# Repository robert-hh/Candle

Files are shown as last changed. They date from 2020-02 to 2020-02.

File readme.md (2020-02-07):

# Just another candle simulation

I made this little code in 2015, when I had a demand for a LED
based candle, and everything I found was either ugly
or just did not look "natural". The ugly ones are those
you get for almost no money, consisting of a battery pack
and a flicker LED, which switches brightness in a few
steps in fast random times.

So I made this one, based on a Attiny85 which replays
short sequences of brightness variations which I captured
from a real candle. I captured the brightness at a rate
of 10 samples/sec, and the code plays 30 samples/sec,
calculating the interim steps between each captured 
value. 
The repository contains a few captured data sets. Each
data set contains 16 sequences of different length, which
are replayed in random order.

Besides that, the code has two additional functions:

- It checks the voltage of the battery, which in my
case is a Li-Ion type. Below ~2.8 the controller 
gets into sleep mode. That saves the battery from 
damage. The sleep current is below 1 µA.
- You can connect a LDR to check for the environmental
brightness. If connected, the candle will pause e.g.
during the day, saving battery power. At daytime, the
sun is much brighter that the LED.

I use it with a 700mAh rechargeable battery. At an
average current of 7mA, it lasts net for 100 hours, or
about a week, when it is off at daytime.

There are two PCB layouts included, which fit nicely 
on a CR123 battery holder. They use different form
factors of the Attiny85, DIL or SOIC. For the DIL, I
bend the pins sideways and then solder it to the surface 
of the PCB. That way, the PCB sits flat beneath the
battery holder. The circuit is protected against
inserting the battery in the wrong orientation.

For use, I take a sufficiently large candle, diameter >65mm,
let it burn down sich that is has a nice shape, with a cavity
of ~2cm at the top. Then I make a hole in the bottom for the
battery holder with the PCB, connect the LED and the LDR, 
and then I'm done. The only problem with that approach is,
that wax melts in the sun. So do not expose it to direct 
sunlight. Otherwise you get candles in Salvador Dali style.
Even then, I have to replace the wax part sometimes. It gets
dirty after a while.

Note: If you ask, what the relation to Micropython is:
I used a PyBoard 1.0 and a LDR to capture the brightness 
pattern of a real candle, and a Python script for normalizing
the data and cutting it into appropriate segments.

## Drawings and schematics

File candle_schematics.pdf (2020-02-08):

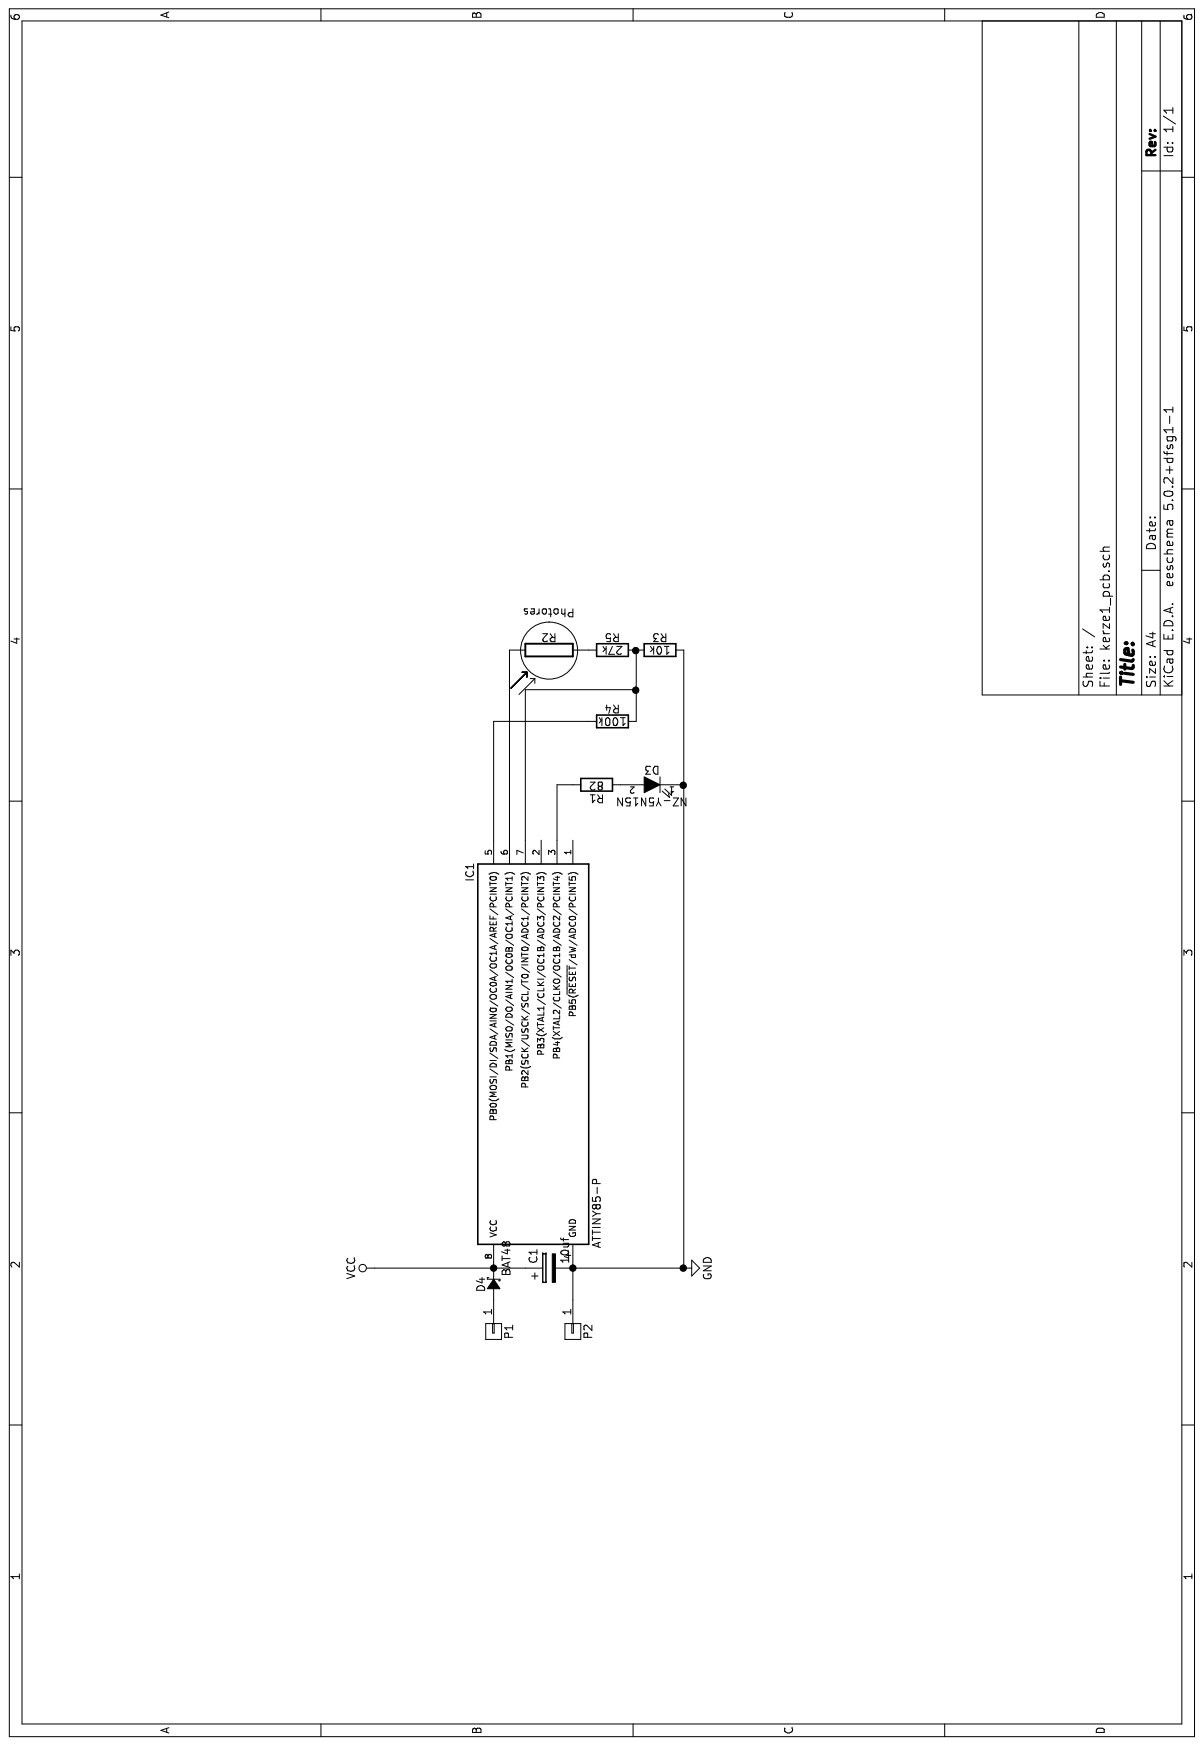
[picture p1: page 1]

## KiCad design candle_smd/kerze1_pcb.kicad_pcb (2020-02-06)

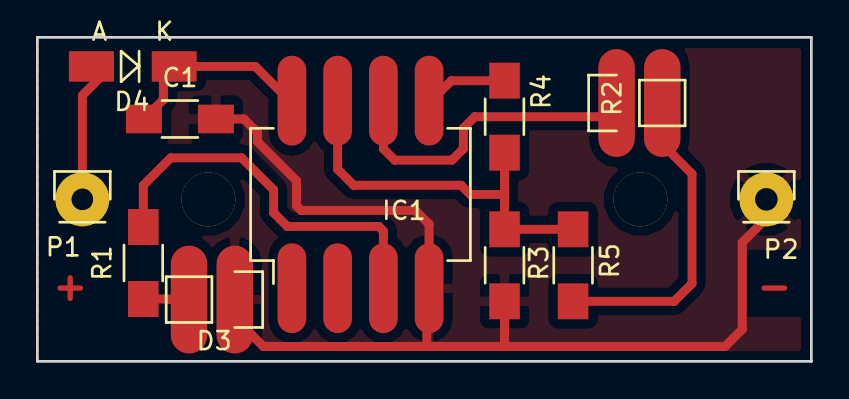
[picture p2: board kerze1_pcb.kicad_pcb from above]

Board: 2 copper layers, 43.0 x 18.0 mm, 13 parts (0 on the bottom side), 9 nets.

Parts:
 : SolderWirePad_single_2mmDrill
 #2: SolderWirePad_single_2mmDrill
C1: 10uf; C_1206_HandSoldering
D3: +LED-; Pin_Header_Straight_1x02
D4: BAT48; MiniMELF_Standard
IC1: ATTINY85-P; DIP-8_W7.62mm_LongPads
P1, P2: Pin_Header_Straight_1x01
R1: 82; R_1206_HandSoldering
R2: Photores; Pin_Header_Straight_1x02
R3: 10k; R_1206_HandSoldering
R4: 100k; R_1206_HandSoldering
R5: 27k; R_1206_HandSoldering

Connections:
GND: C1.2, D3.1, IC1.4, P2.1, R3.2
unnamed: D3.2, R1.1
unnamed: D4.2, P1.1
unnamed: IC1.3, R1.2
unnamed: IC1.5, R4.1
unnamed: IC1.6, R2.1
unnamed: IC1.7, R3.1, R4.2, R5.2
unnamed: R2.2, R5.1
VCC: C1.1, D4.1, IC1.8

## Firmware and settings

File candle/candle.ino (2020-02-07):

// Eine LED mit 256 Stufen
// the setup routine runs once when you press reset:
#include <avr/pgmspace.h>
#include <avr/interrupt.h>
#include <avr/power.h>
#include <avr/sleep.h>
#include <avr/wdt.h>
//#include <avr/cores/tiny/core_adc.h>

// Data captured from a real candle, 1 per byte
#include "data_4.h"

#define VCC_PIN 0 // Ouput for Vcc measuring
#define LDR 1 //  Output controlling LDR
#define LED1 4 // Output of LED
#define SENSE 1 // Number of ADC
#define SENSE_PIN 2 //Number of port PIN for ADC1
#define STATUS 4

uint8_t ldr_state;
uint8_t vcc_state;
uint16_t prev;

#define OFF_LIMIT 850 // 800 // Values normalized for 3.7 V Vbat
#define ON_LIMIT  750 //700
#define VCC_LOW 207  // 2.75V: (Vcc - 0.3) * 1024/12.1
#define VCC_HIGH 220 // 2.9V: (Vcc - 0.3) * 1024/12.1

#define DEBUGLED 0

void wdt_init(void) __attribute__((naked)) __attribute__((section(".init1")));

void wdt_init(void)
{
    MCUSR = 0;
    wdt_disable();

    return;
}

void setup()
{
    // initialize the digital pins
#ifdef _AVR_IOTNX5_H_
    WDTCR |= (1 << WDIE); // reenable interrupt to prevent system reset
    // digitalWrite(LED_BOARD, LOW);
    power_usi_disable();
    ACSR |= _BV(ACD);                         //disable the analog comparator
//    analogReference(ADC_Reference_Internal_1p1);
    analogReference(INTERNAL1V1);
#else
    WDTCSR |= (1 << WDIE); // reenable interrupt to prevent system reset
#endif
    pinMode(LED1, OUTPUT); //LED on Model A
    pinMode(SENSE_PIN, INPUT);
    pinMode(VCC_PIN, INPUT);
    pinMode(LDR, INPUT);
#if DEBUGLED
    pinMode(STATUS, OUTPUT);
#endif
//    digitalWrite(LDR, HIGH);
    ldr_state = 1;  // start with light on
    vcc_state = 1;
// read LDR to seed RNG
    pinMode(LDR, OUTPUT);
    digitalWrite(LDR, HIGH);
    myrand(analogRead(SENSE) & 0xff);
    digitalWrite(LDR, LOW);
    pinMode(LDR, INPUT);

}

// the loop routine runs over and over again forever:
void loop()
{
    uint8_t index, mode;
    uint16_t offset, len, bright, vcc;

// Read VCC
    pinMode(VCC_PIN, OUTPUT);
    digitalWrite(VCC_PIN, HIGH);
    vcc = analogRead(SENSE);
    digitalWrite(VCC_PIN, LOW);
    pinMode(VCC_PIN, INPUT);

// Read LDR
    pinMode(LDR, OUTPUT);
    digitalWrite(LDR, HIGH);
    bright = analogRead(SENSE);
    digitalWrite(LDR, LOW);
    pinMode(LDR, INPUT);

// compensate brightness for changing vcc
    len = ((vcc * 121 + 512) >> 10) + 3;  // 10 times actual Vcc after Diode, rounded
    bright = (bright * 34) / len; // 34 = 10 times (mean Vcc - 0.3V)

#if DEBUGLED
    digitalWrite(STATUS, vcc_state);
#endif

    if (ldr_state != 0 && vcc_state != 0) {  // LED flickers
        wdt_disable();
        index = myrand(0) & 0x0f;
        offset = pgm_read_word_near(offset_tbl + index) >> 1;
        len = (pgm_read_word_near(offset_tbl + index + 1) >> 1) - offset;
        section(offset, len);  // Display
// Test LDR
        if (bright > OFF_LIMIT) { // Daytime, switch off
            ldr_state = 0;
            analogWrite(LED1, 0); // Switch off
        }
// Test VCC
        if (vcc < VCC_LOW) {  // Battery low, switch off
            vcc_state = 0;
            analogWrite(LED1, 0); // Switch off
        }
    } else {

        system_sleep(WDTO_8S, SLEEP_MODE_PWR_DOWN);  // Sleep for 8 sec.

// Test LDR
        if ((ldr_state == 0) && (bright < ON_LIMIT)) {  // Nighttime, switch on
            ldr_state = 1;
        }
// Test VCC, in case the battery recovers
        if ((vcc_state == 0) && (vcc > VCC_HIGH)) {
            vcc_state = 1;
        }
    }
}
// display a section
void section(uint16_t offset, uint16_t len)
{
    int i;
    uint16_t val;

    for (i = 0; i < len; i++) {
        val = pgm_read_byte_near(bright + offset + i); // one values per byte
        if (val < 128) {
            val = (val * val) >> 7;
        } else {
            val = 256 - val;
            val = 255 - ((val * val) >> 7);
        }
        blink(val);  //
    }

}
// display a value
void blink(uint16_t val)
{
    analogWrite(LED1, (val + 2 * prev) / 3); // interim step
    delay(33);
    analogWrite(LED1, (val * 2 + prev) / 3); // interim step
    delay(33);
    analogWrite(LED1, val);
    delay(33);
    prev = val;
}

// Additive RNG along Donal Knuth

uint8_t myrand(uint8_t noise)
{
    static uint8_t set[] = {
        21,  49, 217,  45,   6,  22, 161,  31,  61, 231,
        169,  17,  42, 173, 218, 194, 186, 170,  20,  89,
        44, 138, 163,  58,  30,  34, 220,  31, 134, 130,
        36,  42,  20,  98, 246,  23, 124, 121,  48,  16,
        92,   8,  82,  64,  94,  11, 250,  64, 214, 164,
        88,  87,  67, 225,  23
    };
    static uint16_t k = 54;
    static uint16_t j = 23;
    static uint16_t modulus = 256;
    uint8_t retval;
    int8_t i;

    if (noise != 0) {
        for (i = 0; i < sizeof(set); i++) {
            set[i] = (set[i] + noise) % modulus;
        }
    }

    set[k] = (set[k] + set[j]) % modulus;
    retval = set[k];
    k = (k - 1) % sizeof(set);
    j = (j - 1) % sizeof(set);
    return retval;
}

//****************************************************************
// set system into the sleep state
// system wakes up when wtchdog is timed out
void system_sleep(int duration, int mode)
{
    wdt_enable(duration);
    set_sleep_mode(mode); // sleep mode is set here
    wdt_reset();
#ifdef _AVR_IOTNX5_H_
    WDTCR |= (1 << WDIE); // reenable interrupt to prevent system reset
    ADCSRA &= ~_BV(ADEN);                     //disable ADC
#else
    WDTCSR |= (1 << WDIE); // reenable interrupt to prevent system reset
#endif

    sleep_enable();
    sleep_bod_disable();
    sleep_cpu();
    sleep_disable();                     // System continues execution here when watchdog timed out
#ifdef _AVR_IOTNX5_H_
    ADCSRA |= _BV(ADEN);                     //enable ADC
#endif
}

//****************************************************************

ISR(WDT_vect)
{
    wdt_disable();
}

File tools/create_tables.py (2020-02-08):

#
# nomalize test data

def norm(fname):

    steps = 256
    tailsize = 1000

    liste = []
    with open(fname) as f:
        for l in f:
            liste.append([int(i, 10) for i in l.split(' ')])
        
    print ("Anzahl Daten", len(liste))

## Mittelwerte bestimmen    
    
    minvalue1 = 4096
    maxvalue1 = 0
    minvalue0 = 4096
    maxvalue0 = 0
    avg0 = 0
    avg1 = 0

    for i in liste:
        minvalue0 = min(minvalue0, i[0])
        maxvalue0 = max(maxvalue0, i[0])
        minvalue1 = min(minvalue1, i[1])
        maxvalue1 = max(maxvalue1, i[1])
        avg0 += i[0]
        avg1 += i[1]
            
    avg0 /= len(liste)            
    avg1 /= len(liste)            
    
    print("Min0 = ", minvalue0, ", Max0 = ", maxvalue0, "avg0 = ", avg0)
    print("Min1 = ", minvalue1, ", Max1 = ", maxvalue1, "avg1 = ", avg1)
## Mittelwerte Anfang und Ende bestimmen    
    avghead0 = 0
    avghead1 = 0
    for i in range (0,tailsize):
        avghead0 += liste[i][0]
        avghead1 += liste[i][1]
    
    avgtail0 = 0
    avgtail1 = 0
    for i in range (-(tailsize + 1),-1):
        avgtail0 += liste[i][0]
        avgtail1 += liste[i][1]
    
    avghead0 /= tailsize
    avgtail0 /= tailsize
    avghead1 /= tailsize
    avgtail1 /= tailsize
    print("avghead0 = ", avghead0, ", avgtail0 = ", avgtail0)
    print("avghead1 = ", avghead1, ", avgtail1 = ", avgtail1)
# Kurve kippen    
    avgstep0 = (avgtail0 - avghead0)/len(liste)
    avgstep1 = (avgtail1 - avghead1)/len(liste)
    
    
    for i in range(len(liste)):
        liste[i][0] -= int(i * avgstep0)
        liste[i][1] -= int(i * avgstep1)
## Nochmals Mittelwerte bestimmen
    minvalue1 = 2000000000
    maxvalue1 = 0
    minvalue0 = 2000000000
    maxvalue0 = 0
    
    for i in liste:
        minvalue0 = min(minvalue0, i[0])
        maxvalue0 = max(maxvalue0, i[0])
        minvalue1 = min(minvalue1, i[1])
        maxvalue1 = max(maxvalue1, i[1])
            
    print("Min0 = ", minvalue0, ", Max0 = ", maxvalue0)
    print("Min1 = ", minvalue1, ", Max1 = ", maxvalue1)
    
    avghead0 = 0
    avghead1 = 0
    for i in range (0,tailsize):
        avghead0 += liste[i][0]
        avghead1 += liste[i][1]
    
    avgtail0 = 0
    avgtail1 = 0
    for i in range (-(tailsize + 1),-1):
        avgtail0 += liste[i][0]
        avgtail1 += liste[i][1]
    
    avghead0 /= tailsize
    avgtail0 /= tailsize
    avghead1 /= tailsize
    avgtail1 /= tailsize
    print("avghead0 = ", avghead0, ", avgtail0 = ", avgtail0)
    print("avghead1 = ", avghead1, ", avgtail1 = ", avgtail1)
        
    divide0 = ((maxvalue0 - minvalue0 + 1) / steps)
    divide1 = ((maxvalue1 - minvalue1 + 1) / steps)
    
    avg0 = 0
    avg1 = 0
    for i in range(len(liste)):
        liste[i][0] = int((liste[i][0] - minvalue0) / divide0)
        liste[i][1] = int((liste[i][1] - minvalue1) / divide1)
        avg0 += liste[i][0]
        avg1 += liste[i][1]
    avg0 = int(avg0/len(liste)) 
    avg1 = int(avg1/len(liste)) 
# und nochmals mittelwerte

    minvalue1 = 4096
    maxvalue1 = 0
    minvalue0 = 4096
    maxvalue0 = 0

    for i in liste:
        minvalue0 = min(minvalue0, i[0])
        maxvalue0 = max(maxvalue0, i[0])
        minvalue1 = min(minvalue1, i[1])
        maxvalue1 = max(maxvalue1, i[1])
    
    print("Min0 = ", minvalue0, ", Max0 = ", maxvalue0, "avg0 = ", avg0)
    print("Min1 = ", minvalue1, ", Max1 = ", maxvalue1, "avg1 = ", avg1)
    
    with open(fname + "lr", "w") as f:
        for i in liste:
            f.write("%d %d\n" % (i[0], i[1]))

    
    with open(fname + "f1.h", "w") as f:
        f.write("const PROGMEM  uint8_t bright[] = {")
        for i in range(len(liste)):
            if (i % 20) == 0:
                f.write("\n    ")
            f.write("%d" % liste[i][0])
            if i < len(liste) - 1: 
                f.write(", ")
        f.write("\n};\n")

        f.write("const PROGMEM uint16_t offset_tbl[] = {\n")
        
        j = 0
        while j < len(liste):
            if abs(liste[j][0] - avg0) < 10:
                f.write("%d, " % j)
                print(j, ", ", end = "")
                j += len(liste) // (17)
            else:
                j += 1
        f.write("%d\n};\n" % len(liste))
        print()
        
    
    with open(fname + "f2.h", "w") as f:
        f.write("const PROGMEM  uint8_t bright[] = {")
        for i in range(len(liste)):
            if (i % 20) == 0:
                f.write("\n    ")
            f.write("%d" % liste[i][1])
            if i < len(liste) - 1: 
                f.write(", ")
        f.write("\n};\n")

        f.write("const PROGMEM uint16_t offset_tbl[] = {\n")
        
        j = 0
        while j < len(liste):
            if abs(liste[j][1] - avg1) < 10:
                f.write("%d, " % j)
                print(j, ", ", end = "")
                j += len(liste) // (17)
            else:
                j += 1
        f.write("%d\n};\n" % len(liste))
        print()
        
    print (len(liste))
